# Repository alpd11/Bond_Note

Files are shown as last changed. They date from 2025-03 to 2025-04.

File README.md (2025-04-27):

<p align="center">
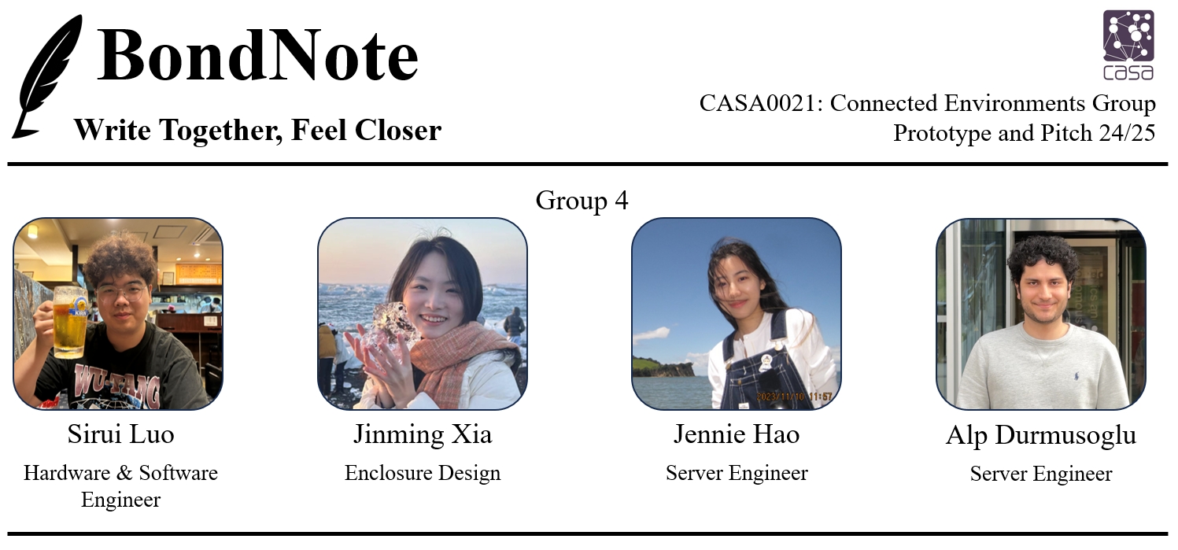
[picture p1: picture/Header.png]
Team
  <br>
</p>

### Project Video:
<p align="center">
  <a href="https://www.youtube.com/watch?v=klF6RZovyqQ" target="_blank">
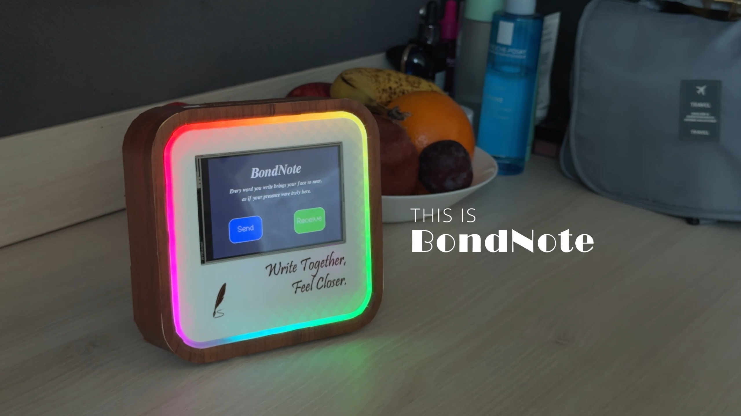
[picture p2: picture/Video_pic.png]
BondNote Video
    
  </a>
</p>

# ✍️ Whats is BondNote?
BondNote is a connected handwriting device designed to restore emotional warmth to digital communication (Fig.1). The project realises real-time transmission and dynamic reproduction of handwritten content by connecting two physical handwriting tablets. Its core design concept is ‘Bring warmth back into communication - because some messages deserve more than just text’.

<p align="center">
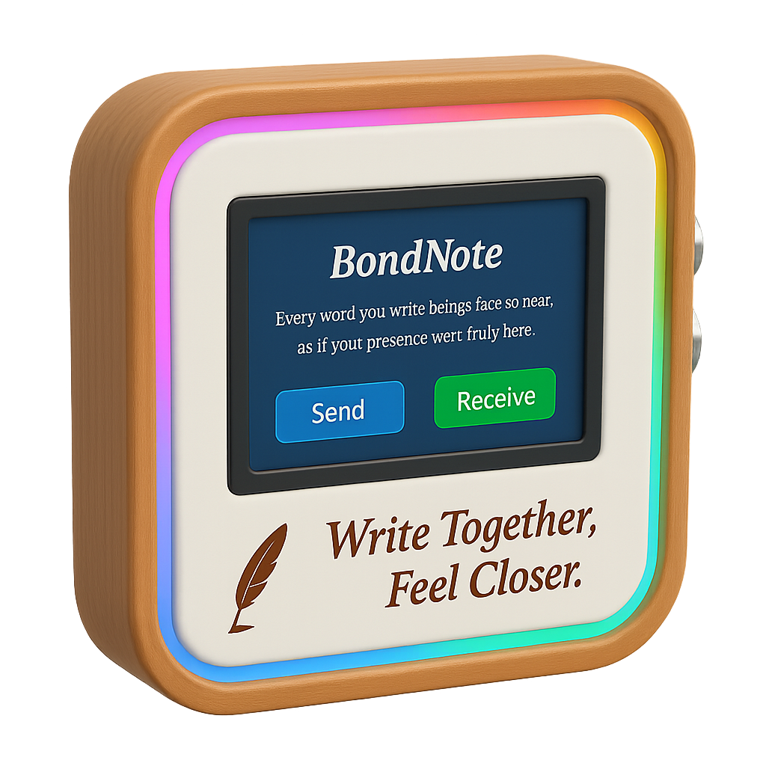
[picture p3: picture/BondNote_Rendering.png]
BondNote_Rendering
  <br>
  <span style="font-size: 14px; color: gray;"><b>Fig.1</b> BondNote rendering picture</span>
</p>

# 📑 Table of Contents

- [Why BondNote Is Useful](#-why-bondnote-is-useful)
- [Getting Started](#-getting-started)
- [How to use it](#-how-to-use-it)
- [Product Special Features](#-product-special-features)
- [Future Work](#-future-work)
- [Contributions](#-contributions)
- [Budget List](#-budget-list)
- [References](#references)

---

# 💡 Why BondNote Is Useful
<!-- 讲清楚使用场景、痛点与收益，展示价值主张。 -->
In today's digital world, the rapid development of technology has led to the gradual replacement of traditional handwriting by digital devices to dominate our conversations (Kiefer et al., 2015). Take WhatsApp, Messenger, and other popular instant messengers as an example, although they have greatly improved the efficiency of information transmission, they have become ‘flat’ because of their over-reliance on standardized text and emoticons. Different from the mechanical recognition of printed text, the writing and reading of handwritten text involve a complex process of linguistic and visual processing in the brain, and its personalized features carry emotional memory information (Ren et al., 2018).

In addition, the technology usability divide is particularly pronounced among specific groups. Pew Research Center (2017) found that 34% of older internet users say they have little to no confidence in their ability to use electronic devices to perform online tasks.
In the family scenario, parents often need to establish ‘lightweight’ remote communication with their younger children. However, existing solutions, such as equipping children with personal devices like smartphones, have many drawbacks. Children who are exposed to mobile phones early and excessively are more likely to have shortened attention spans, anxiety, and problems with social interactions (EdSource, 2024). Longcamp et al. (2005) showed that handwriting activities promote cognitive development by enhancing the perceptual-motor connection and helping children to better recognize and remember letters.

<p align="center">
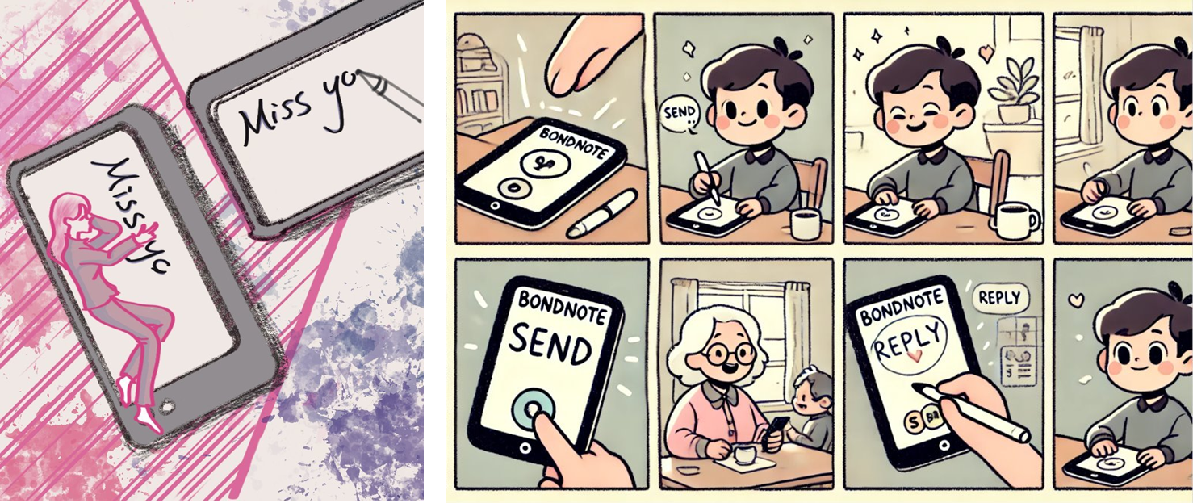
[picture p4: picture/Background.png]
  <br>
  <span style="font-size: 14px; color: gray;"><b>Fig.2</b> Target users</span>
</p>

Therefore, we identified the target users of our product (Fig.2):
-  ***Long-distance companions*** : need strong emotional connection and companionship, not cold digital information.
- ***The elderly and children***: need a simple and intuitive interactive system.

---
# 🚀 Getting Started

## Hardware List

To build and run this project, you will need the following hardware:

<div align="center">

| Item | Quantity | Description/Note |
|--- |:---:|---|
| **ESP32 DEVKITV1** | 1 | Main microcontroller board |
| **4-inch LCD TFT Touch Display** | 1 | ili9488 chip |
| **Buttons** | 2 | For user input |
| **WS2812 RGB LED Strip** | 1 | Individually addressable LEDs |
| **Power Supply** | 1 | For powering ESP32 and peripherals |
| **BondNote PCB** | 1 | Or it could be replaced as breadboard in Fig.3 |
| **Jumper wires** | multiple | Female-female, male-female, as needed |

</div>

***ps***: The BondNote PCB's Gerber file is in this repository. If you want to use this please upload this to any of the EDA manufacturers for building.

## Setup Steps

**1. Wiring:**  
<p align="center">
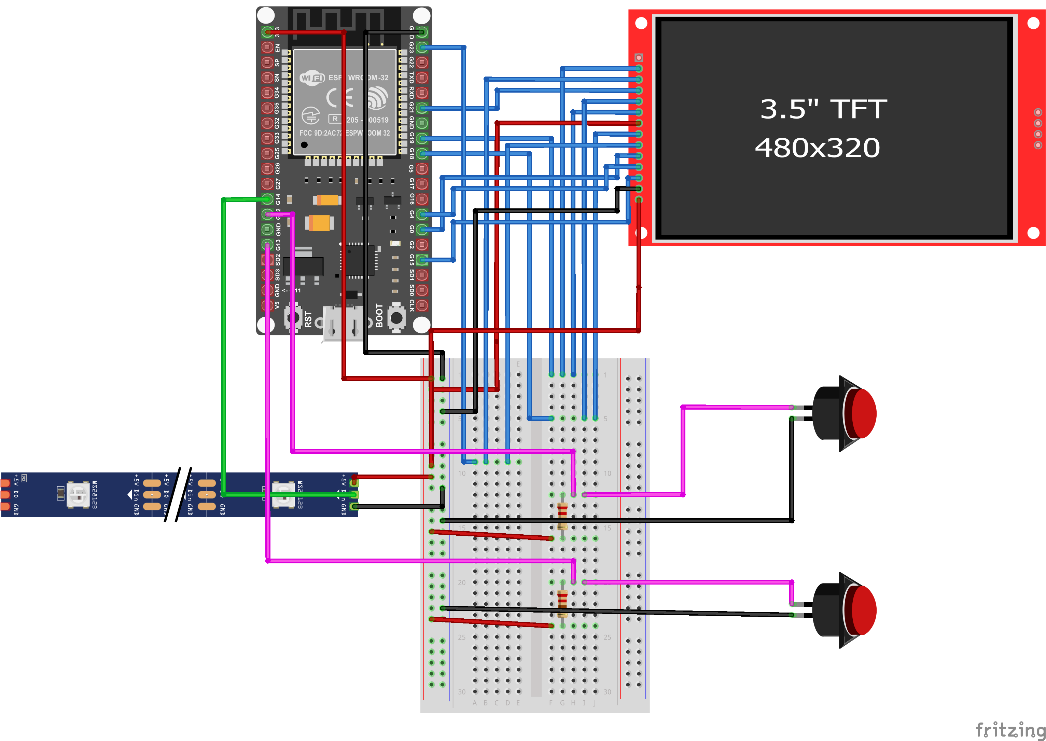
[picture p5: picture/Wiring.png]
  <br>
  <span style="font-size: 14px; color: gray;"><b>Fig.3</b> Wiring illustraion</span>
</p>

   - Connect the ESP32 to the LCD display following the ili9488 pinout.
   - Attach the two buttons to available digital pins on the ESP32 (remember to use pull-down or pull-up resistors as needed).
   - Connect the WS2812 LED strip data line to a suitable ESP32 GPIO, and provide appropriate power (typically 5V).
   - Power your ESP32 and peripherals using the power supply and jumper wires.

**2. Software Installation & Flashing the Code:**  
   - Install the [Arduino IDE](https://www.arduino.cc/en/software) on your computer.
   - Add the ESP32 board package to your IDE.
   - Install the necessary libraries:
     - `TFT_eSPI` (for ili9488 display)
     - `Adafruit_NeoPixel` (for WS2812 LED strip)
     - Clone this repository and flash **Bond_Note/BondNote_Code/BondNote.ino** to the ESP32 board

---
# 💻 How to use it
<p align="center">
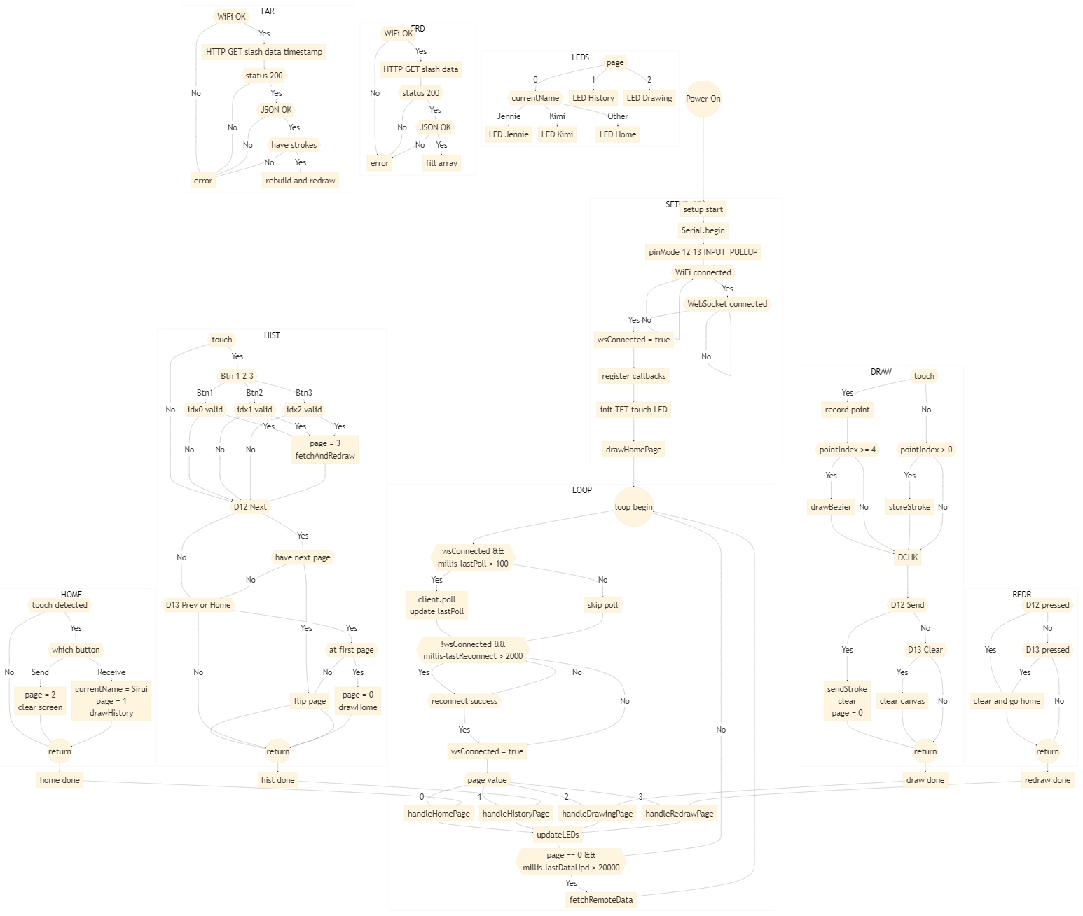
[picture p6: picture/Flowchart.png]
  <br>
  <span style="font-size: 14px; color: gray;"><b>Fig.4</b> Functions flowchart of BondNote</span>
</p>

The internal software of **BondNote** integrates a variety of functions and UI interfaces to ensure a warm and intuitive user experience. Below is a summary of the major functionalities and button interactions:

## ✉️ Core Functions: Sending and Receiving

### 1. Sending Handwritten Messages
- **Workflow:**
  - When the user clicks the "Send" button on the main interface, they enter the handwriting editing page.
  - On this page, users can freely write their message.
  - There are two physical buttons on the right side of the device:
    - **Upper button:** Confirm and send the current handwritten message.
    - **Lower button:** Erase the current handwriting (clear the canvas).

### 2. Receiving and Viewing Messages
- **Workflow:**
  - The Receive page provides a functional UI for browsing message history.
  - Users can use the two physical buttons to **page up** or **page down** through historical messages.
  - Messages from different senders are marked by their user name and distinct color (e.g., Jennie's messages in yellow, Kimi's messages in green).
  - After selecting a message, clicking it enters the "Redrawing" page, where the original handwriting process is dynamically displayed on the screen, enhancing the sense of real-time interaction.

## 🌈 Light Strip Notification & Real-time Listening

- On the welcome page, the software uses a WebSocket Echo listening function (`client.poll`) to constantly check for new messages from the server.
- When a new message is detected:
  - The sender's information is retrieved.
  - The RGB LED strip changes from a rainbow effect to a **breathing light** corresponding to the sender's color (e.g., Jennie = yellow breathing light, Kimi = green breathing light).
  - This real-time color change visually alerts users that a new message has arrived and helps identify the sender at a glance.

## 🔘 Button Interaction Overview
<div align="center">

| Page | Upper Button Function | Lower Button Function |
|---|---|---|
| **Welcome** | No response | No response |
| **Send** | Send message | Erase handwriting |
| **Receive** | Page up | Page down |
| **Message Redrawing** | Exit to Home | Exit to Home |

</div>

# 🌟 Product Special Features

## 🛠️ Hardware
**PCB Design & Fabrication:**  
<p align="center">
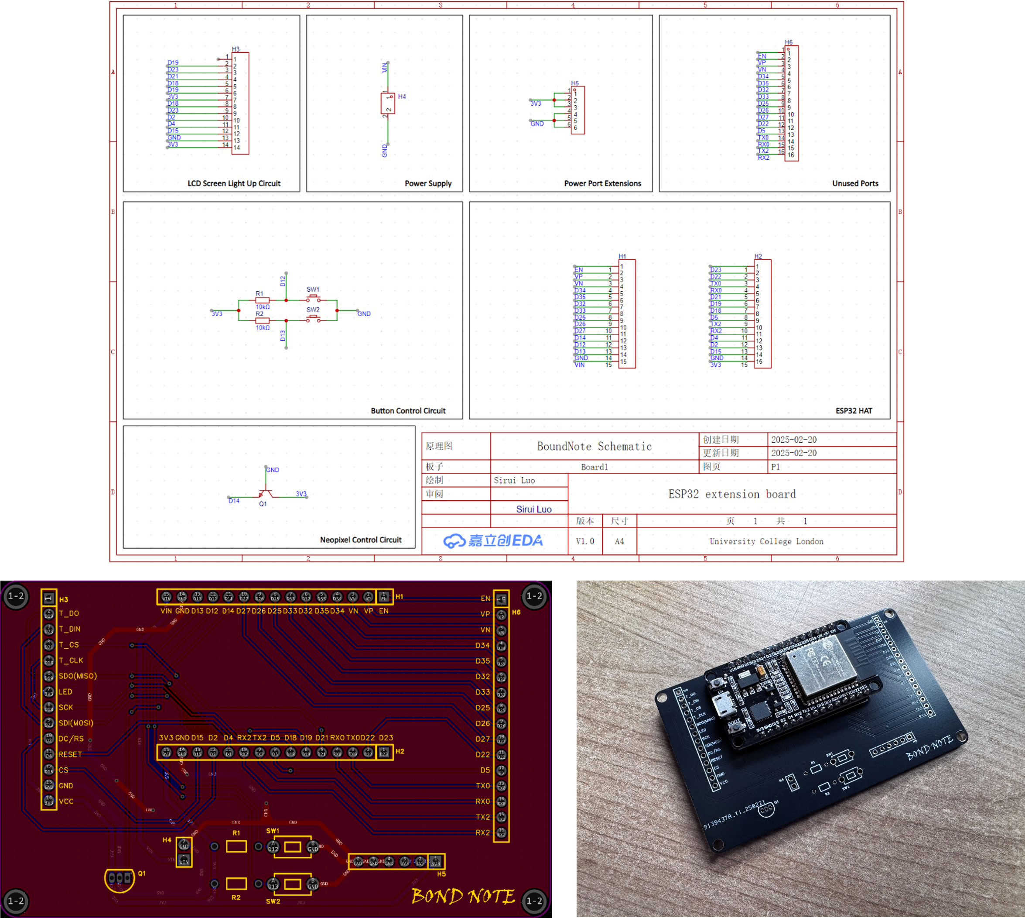
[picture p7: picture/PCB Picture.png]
  <br>
  <span style="font-size: 14px; color: gray;"><b>Fig.5</b> PCB schematic, wiring and material object</span>
</p>
We used EasyEDA Professional Edition to finish principle diagram drawing and PCB wiring design, and employed JLC international contract manufacturing service for PCB board manufacturing. The PCB board adopted the mode of expansion board design, and ESP32 DEVKIT1 development board was placed on the top layer. Then, connections with various components were designed based on different sectors to realize clear module division and efficient layout arrangement (Fig.5). 

## 💻 Software
**Real-time Communication:**  
BondNote once utilized the MQTT protocol in the early-stage design. However, the connection mode of MQTT is more suitable for light-weight data transmission, and it is not applicable to high-frequency data interaction. It can hardly realize the product's core function, namely synchronous handwriting trace representation. We finally chose WebSocket protocol as the alternative solution. 
WebSocket protocol can establish a permanent channel for real-time communication between the client end and the server, which significantly improves the response speed of application programs. It has characteristics like stabler long connection, lower transmission delay, etc., and it is particularly suitable for handwriting data transmission with manifest demands for real-time interactions. In addition, WebSocket can also manage multiple concurrent client end connections, which is vital for products needing simultaneous interactions among multiple users like BondNote.

**MongoDB and Heroku cloud platform integration:**  
As a NoSQL database, MongoDB is good at processing structured and semi-structured data, and it can store message coordinates, time stamps and users' information. It is very suitable for BondNote handwriting data coordinate storage. It can also provide powerful inquiry function, efficient data organization and fast interactive retrieval for users. 
Heroku, a cloud platform-as-a-service (PaaS), hosts the backend API, providing the necessary infrastructure for scalability, ease of deployment, and maintenance-free operation. The API hosted on Heroku seamlessly bridges the WebSocket protocol with MongoDB, enabling real-time data transactions between users and the database. Using Heroku’s managed services reduces operational overhead, ensures high availability, and facilitates continuous integration and deployment (CI/CD) practices, making it an ideal solution for Bond Note's infrastructure requirements.

**Structured Data Management:**  
Since the RAM space of ESP32 is relatively small, with limited processing capacity, we gave up the idea of using graphic data and turned to use light-weight Json format (Fig.8) to store and transmit handwriting data. During the process of storage and transmission, data coordinates are organized through time sequences to generate various arrays, which should be traversed in succession to realize real-time handwriting trace representation and guarantee efficient transmission and quick reading of data. 
<p align="center">
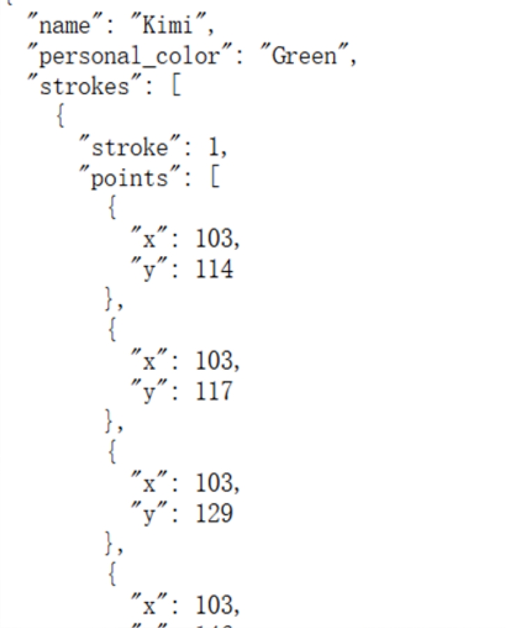
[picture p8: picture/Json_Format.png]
  <br>
  <span style="font-size: 14px; color: gray;"><b>Fig.6</b> Json formatted data</span>
</p>

**Handwriting Algorithm Optimization:**  
Since traditional eSPI library has poor ability of processing continuously handwriting traces, and the screen hardware's refresh rate is also limited, handwriting traces written by built-in functions in the library are always not ideal enough. Upon research, we found that Bezier curve algorithm can smoothly connect points with a short distance, thus significantly improving smoothness, while points with a long distance may be separated from integral handwriting through the dot painting function of eSPI.  The two can be combined to form a high-quality effect of handwriting (Fig.7). Moreover, this mode has lower computation loads, and there is basically no delay between writing and trace generation, which will not influence users' experience. 

<p align="center">
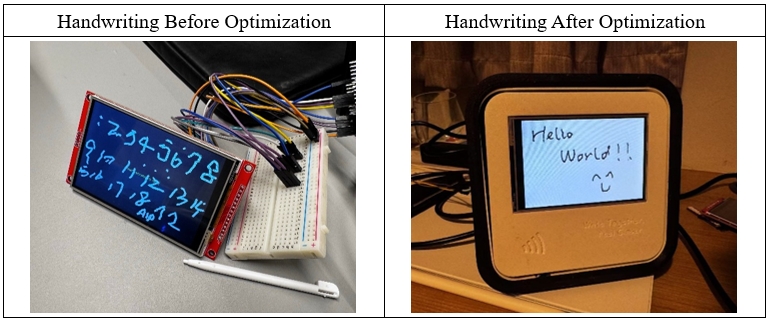
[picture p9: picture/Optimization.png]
  <br>
  <span style="font-size: 14px; color: gray;"><b>Fig.7</b> Before-and-after comparison pictures of optimization</span>
</p>

## 🧩 Model Design
BondNote’s enclosure was designed and modeled in SketchUp, undergoing multiple iterations to achieve a balance between function, emotional needs, and visual aesthetics. The initial design focused on portability and a slim profile, but as the project progressed, we wanted BondNote to stand out from ordinary electronic products and better express emotional warmth. Therefore, the enclosure was gradually redefined as a decorative ornament suitable for family spaces, endowing it with a sculptural sense to create a warmer atmosphere (Fig.8). 
<p align="center">
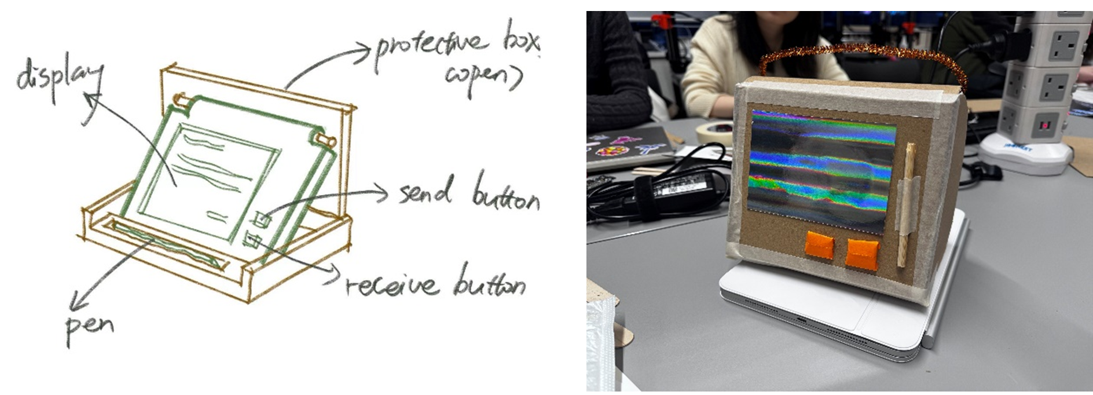
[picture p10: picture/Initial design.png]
  <br>
  <span style="font-size: 14px; color: gray;"><b>Fig.8</b> The initial design and improvements</span>
</p>

With continuous hardware upgrades, the enclosure was resized several times to ensure both comfortable handwriting and screen readability. The internal structure was also repeatedly refined to allow all components to remain stable while maintaining a glue-free assembly, making it easier to maintain and more environmentally friendly (Fig.9).

<p align="center">
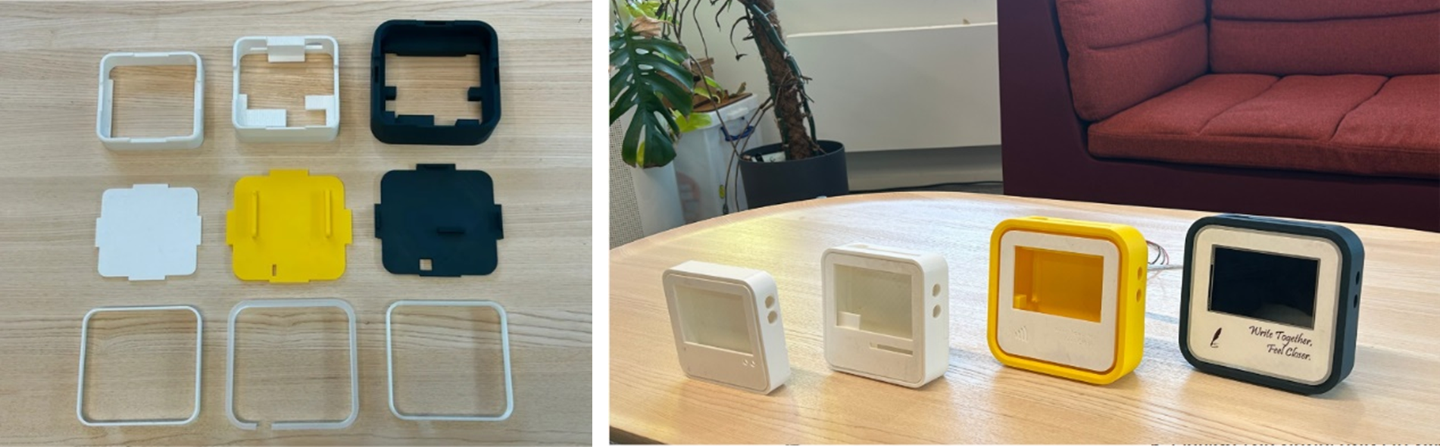
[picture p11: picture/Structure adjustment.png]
  <br>
  <span style="font-size: 14px; color: gray;"><b>Fig.9</b> Size, internal structure and placement angle adjustment</span>
</p>

 To further enhance the user experience, we introduced an inclined placement angle, improving both the ergonomics of handwriting and the clarity of displayed content in different scenarios. The design of the light slot was inspired by desk lamps: the original exposed light bar was upgraded into a concealed, soft-light band to better convey warmth. We explored different materials and surface treatments—such as using sandpaper for a diffused lighting effect—based on both our experiments and professors’ advice, ultimately achieving a gentle ambient glow (Fig.10). 

<p align="center">
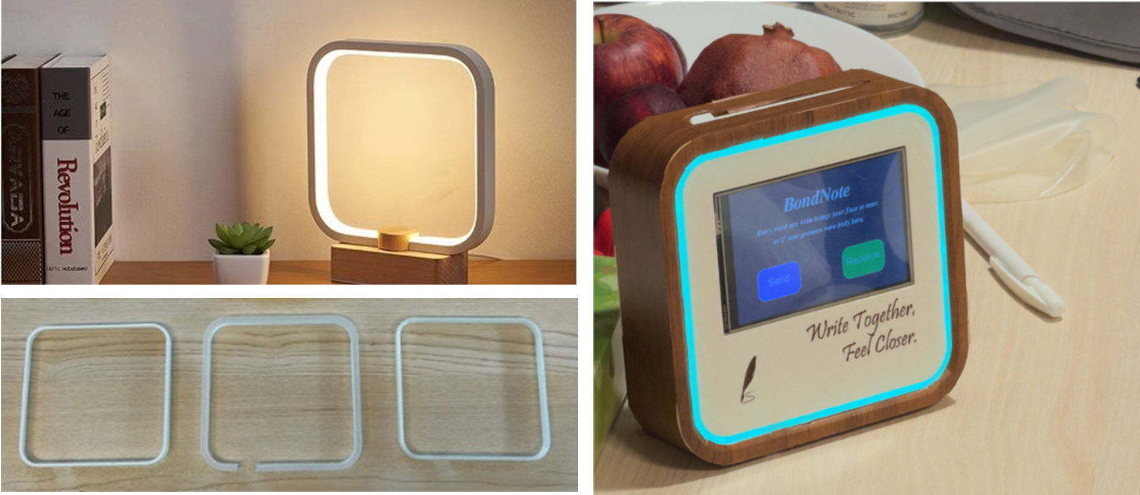
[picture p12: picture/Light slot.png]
  <br>
  <span style="font-size: 14px; color: gray;"><b>Fig.10</b> Light slot design optimization</span>
</p>

---

# 🔮 Future Work

## 3.1 Hardware Upgrade
In the future, we will consider customized and professional PCB production with a high degree of integration to lower costs and improve products' reliability. We will also establish long-term and stable cooperative relations with suppliers to guarantee the security of components' supply chains.

## 3.2 Software Function Expansion
We plan to provide more writing colors and the function of customization, develop mobile-end supporting App for BondNote, and provide functions like equipment initialization, monitoring and management to further improve users' experience.

## 3.3 Enclosure Improvement
In the future, the current PLA enclosure printed based on 3D printing technology may be upgraded as wooden materials to better reflect the product's feature of warm emotions and improve the product's market attraction and texture. 

---

# 🙌 Contributions

- **Sirui Luo:** Hardware selection, circuit construction, PCB design and manufacturing, all software development and deployment, as well as the script, filming, and editing of the project video. Readme file integration.
- **Jiniming Xia:** Enclosure design, manufacturing, and iteration. Project report integration.  Participated in the video as an actress.
- **Jennie Hao:** Server selection and setup, background research, and business analysis. Script formulation for video. Participated in the video as an actress.
- **Alp Durmusoglu:** Node.js server code development and MongoDB server setup and maintenance.

---

# 💰 Budget List

<div align="center">

| Item | Quantity | Price |
|---|:---:|:---:|
| **ESP32 DEVKITV1** | 1 | £7 |
| **4-inch LCD TFT Touch Display** | 1 | £22 |
| **Buttons** | 2 | £2.8 |
| **WS2812 RGB LED Strip** | 1 | £11 |
| **BondNote PCB / Breadboard** | 1 | £1 |
| **Jumper wires** | multiple | £1 |
| **3D Printed Enclosure** | 1 | ≈£5 |
| **Total** | — | **≈£49.8**|

</div>
<br>
PS：We need to deploy a server using Heroku, $5 for 1000 dyno hours/month

---

# 📑References

EdSource (2024) Excessive cell phone use can harm children. Here’s how parents can limit use at home. Available at: https://edsource.org/2024/excessive-cell-phone-use-can-harm-children-heres-how-parents-can-limit-use-at-home/718105 (Accessed: 24 April 2025).

Longcamp, M., Zerbato-Poudou, M.-T. & Velay, J.-L. (2005) The influence of writing practice on letter recognition in preschool children: A comparison between handwriting and typing. Acta Psychologica. 119 (1), 67–79. doi:10.1016/j.actpsy.2004.10.019.

Kiefer, M., Schuler, S., Mayer, C., Trumpp, N.M., Hille, K. & Sachse, S. (2015) Handwriting or Typewriting? The Influence of Penor Keyboard-Based Writing Training on Reading and Writing Performance in Preschool Children. Advances in Cognitive Psychology. 11, 136–146. doi:10.5709/acp-0178-7.

Pew Research Center (2017) Tech adoption climbs among older adults. Available at: https://www.pewresearch.org/internet/2017/05/17/tech-adoption-climbs-among-older-adults/ (Accessed: 24 April 2025).

Ren, X. Q., Fang, X., Sui, X. & Wu, Y. (2018) Characteristics and neural mechanisms of handwritten character recognition. Advances in Psychological Science, 26(7), 1174-1185. doi:10.3724/SP.J.1042.2018.01174

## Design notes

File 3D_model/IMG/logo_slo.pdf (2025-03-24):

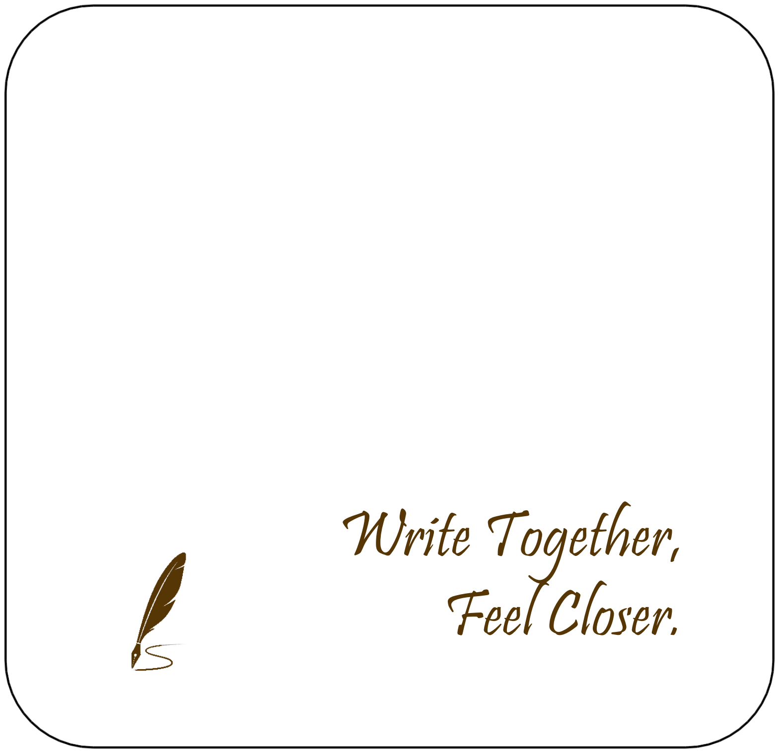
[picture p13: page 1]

WriteTogether,
FeelCloser.

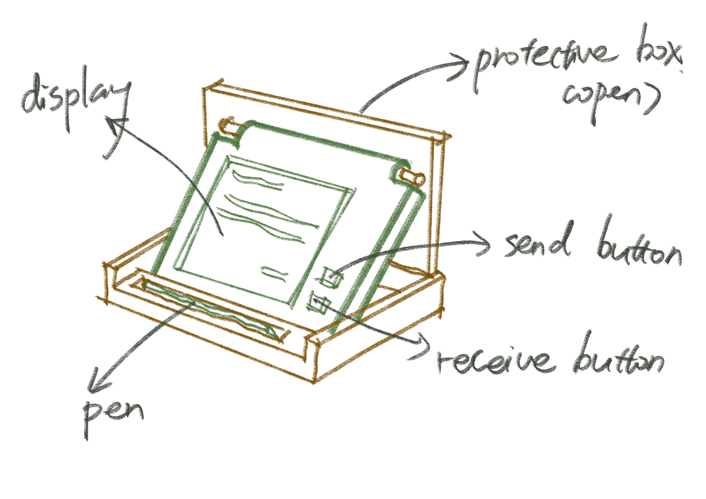
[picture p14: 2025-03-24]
3D_model/IMG/sketch1.jpg

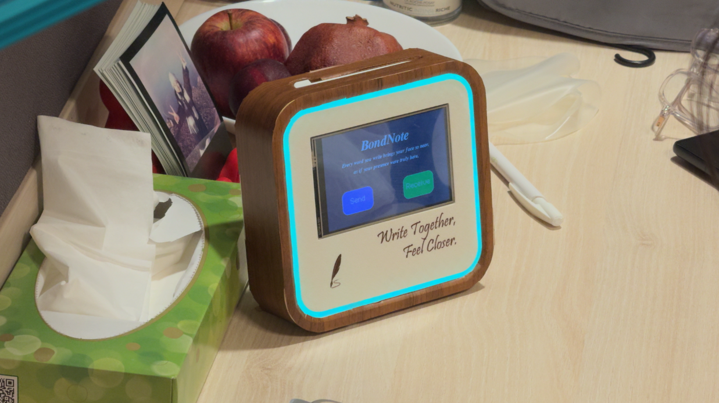
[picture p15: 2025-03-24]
3D_model/IMG/final2.png

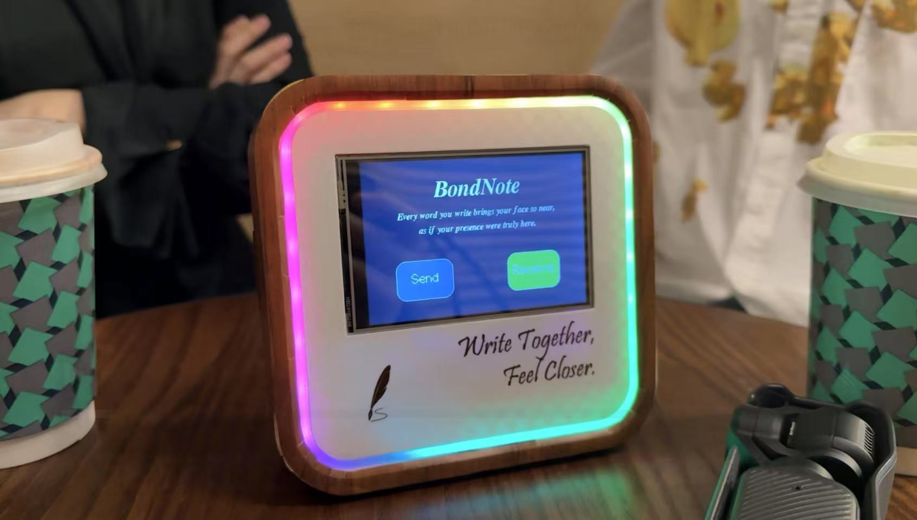
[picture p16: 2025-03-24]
3D_model/IMG/final.jpg

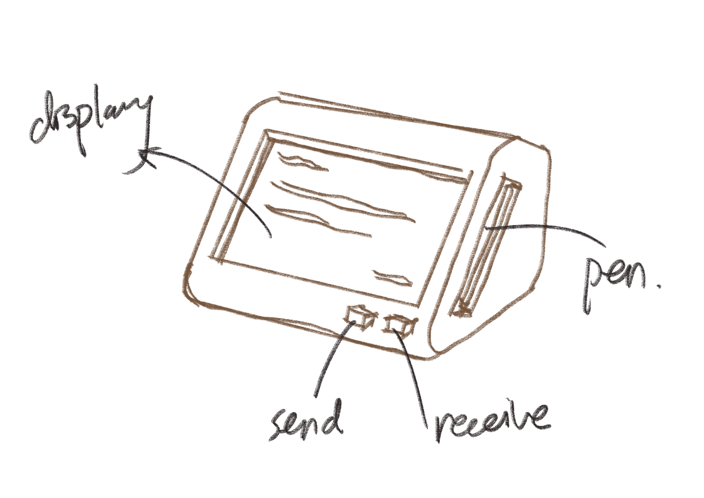
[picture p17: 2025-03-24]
3D_model/IMG/sketch3.jpg

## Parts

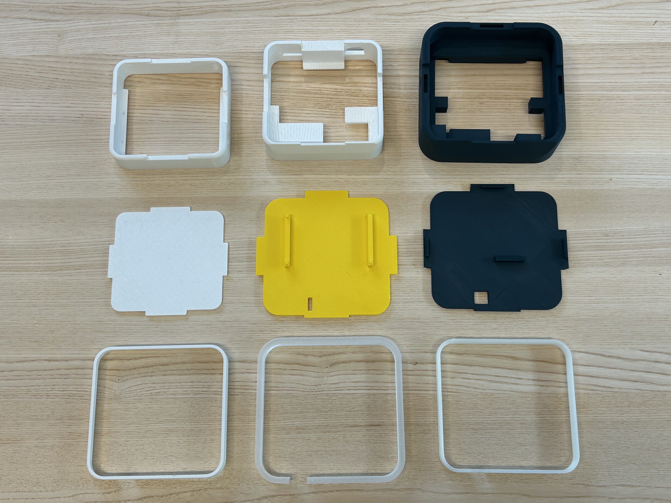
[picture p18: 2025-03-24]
3D_model/IMG/Components.jpg

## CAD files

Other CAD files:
3D_model/MODEL_TEST_0226.skp
3D_model/MODEL_TEST_0303.skp
3D_model/TILT_TEST_0306.skp

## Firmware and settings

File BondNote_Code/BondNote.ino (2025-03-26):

#include <TFT_eSPI.h>
#include <SPI.h>
#include <Arduino.h>
#include <ArduinoJson.h>
#include <WiFi.h>
#include <ArduinoWebsockets.h>
#include <Adafruit_NeoPixel.h>  
#include <HTTPClient.h>             
#include "Free_Fonts.h" 

using namespace websockets;

// **WiFi and WebSocket Configuration**

const char* ssid = "";      // Your WiFi SSID
const char* password = "";  // Your WiFi Password

// WebSocket server
const char* websockets_server_host = "bond-note-c746823b71f7.herokuapp.com";
const uint16_t websockets_server_port = 80;

WebsocketsClient client;
bool wsConnected = false; // WebSocket connection status
unsigned long lastPoll = 0;

// Create TFT_eSPI object
TFT_eSPI tft = TFT_eSPI();

// Two buttons on the home page
TFT_eSPI_Button btnSendMessage;
TFT_eSPI_Button btnReceiveMessage;

// Three buttons on the history messages page
TFT_eSPI_Button btnHistory1;
TFT_eSPI_Button btnHistory2;
TFT_eSPI_Button btnHistory3;

// Fixed known touch calibration data (example values)
uint16_t calData[5] = { 309, 3475, 243, 3519, 1 };

// Screen width and height
#define SCREEN_WIDTH  480
#define SCREEN_HEIGHT 320

// Width and height for each button
#define BTN_W SCREEN_WIDTH
#define BTN_H (SCREEN_HEIGHT / 3)

// Center coordinates for the three history buttons
#define BTN1_CX (SCREEN_WIDTH / 2)
#define BTN1_CY (BTN_H / 2)
#define BTN2_CX (SCREEN_WIDTH / 2)
#define BTN2_CY (BTN_H + BTN_H / 2)
#define BTN3_CX (SCREEN_WIDTH / 2)
#define BTN3_CY (2 * BTN_H + BTN_H / 2)

// Width and height for home page buttons
#define BTN_HOME_W (SCREEN_WIDTH / 4)
#define BTN_HOME_H (SCREEN_HEIGHT / 4)

// Center coordinates for home page buttons
#define BTN_SEND_CX (SCREEN_WIDTH / 4)
#define BTN_SEND_CY (SCREEN_HEIGHT * 3 / 4)
#define BTN_RECEIVE_CX (3 * SCREEN_WIDTH / 4)
#define BTN_RECEIVE_CY (SCREEN_HEIGHT * 3 / 4)

#define MAX_POINTS 100  
#define MAX_STROKES 100 
#define INACTIVITY_TIMEOUT 20000 // 5 seconds of no touch triggers redraw

// LED strip configuration (adjust LED_PIN based on actual wiring)
#define LED_PIN    5   
#define LED_COUNT  45  

Adafruit_NeoPixel strip(LED_COUNT, LED_PIN, NEO_GRB + NEO_KHZ800);

// ============ New: hardware button definitions ============
const int buttonPin12 = 12;  // GPIO12, using internal pull-up
const int buttonPin13 = 13;  // GPIO13, using internal pull-up

// ============ Variables for the writing page ============
uint16_t touchPoints[MAX_POINTS][2]; 
uint8_t pointIndex = 0;              
uint8_t thickness = 2;               
uint8_t strokeIndex = 1;             
unsigned long lastTouchTime = 0;     

struct Stroke {
  uint16_t points[MAX_POINTS][2];
  uint8_t pointCount;            
};
Stroke strokes[MAX_STROKES]; 
uint8_t strokeCount = 0;     

// ============ Page flags: 0-home, 1-history, 2-writing, 3-history strokes display ============
int page = 0;

// ========== Structure to store historical info fetched from the server ========== 
struct DataItem {
  String name;
  String timestamp;
};

#define MAX_DATA_ITEMS 20
DataItem dataItems[MAX_DATA_ITEMS];
int dataCount = 0;

// Refresh data every 5 seconds
unsigned long lastDataUpdate = 0;

// ========== History page pagination ==========
int historyStartIndex = 0;          // Current start index of the history list (0-based)
int buttonIndices[3] = {-1, -1, -1}; // Records the indices in dataItems for the 3 buttons

// ========== New: used to distinguish LED color on the home page ==========
String currentName = "None"; // Used to record the last "name" received from WebSocket

// ================ Function Declarations ================
void drawHomePage();
void drawHistoryPage();
void handleHomePage();
void handleHistoryPage();
void handleDrawingPage();
void handleRedrawPage(); // new

void setupWiFiAndWebSocket();
void fetchRemoteData();

uint32_t Wheel(byte WheelPos);
void updateLEDHome();
void updateLEDHistory();
void updateLEDDrawing();
void updateLEDKimi();
void updateLEDJennie();
void updateLEDs();

void sendStrokeData();
void redrawScreen();
void drawBezierCurve(uint16_t p0[], uint16_t p1[], uint16_t p2[], uint16_t p3[], uint16_t color);
void storeStroke();
void fetchAndRedraw(const String& timestamp);
void drawLoadingScreen();

void setup() {
  Serial.begin(115200);

  // Hardware buttons: internal pull-up
  pinMode(buttonPin12, INPUT_PULLUP);
  pinMode(buttonPin13, INPUT_PULLUP);

  // First connect to WiFi & WebSocket
  setupWiFiAndWebSocket();

  // Initialize screen
  tft.init();
  tft.setRotation(3);
  tft.setTouch(calData);
  tft.fillScreen(TFT_BLACK);

  // Initialize LED
  strip.begin();
  strip.show();
  strip.setBrightness(40); // Lower brightness to avoid glare

  // Draw the home page
  drawHomePage();
}

void loop() {
  // 1) Regardless of which page, periodically poll WebSocket
  if (millis() - lastPoll > 100 && wsConnected) {
    client.poll();
    lastPoll = millis();
  }

  // 2) If wsConnected == false, automatically attempt reconnection
  static unsigned long lastReconnectAttempt = 0;
  if (!wsConnected && millis() - lastReconnectAttempt >= 2000) {
    lastReconnectAttempt = millis();
    Serial.println("Trying to reconnect to WebSocket...");
    wsConnected = client.connect(websockets_server_host, websockets_server_port, "/");
    if (wsConnected) {
      Serial.println("✅ Reconnected!");
    } else {
      Serial.println("❌ Reconnect failed, will retry...");
    }
  }

  // 3) Handle interactions based on the current page
  if (page == 0) {
    handleHomePage();
  } 
  else if (page == 1) {
    handleHistoryPage();
  } 
  else if (page == 2) {
    handleDrawingPage();
  }
  else if (page == 3) {
    handleRedrawPage();
  }

  // 4) Update LEDs based on the current page
  updateLEDs();

  // 5) Periodically perform an HTTP GET to fetch data (only refresh when on home page)
  /*
  if (millis() - lastDataUpdate >= 20000 && page == 0) {
    lastDataUpdate = millis();
    fetchRemoteData();
  }
  */
}

// ================ WebSocket & WiFi Initialization ================
void setupWiFiAndWebSocket() {
  // 1. Connect to WiFi
  WiFi.begin(ssid, password);
  Serial.print("🔄 Connecting to WiFi...");
  while (WiFi.status() != WL_CONNECTED) {
      Serial.print(".");
      delay(1000);
  }
  Serial.println("\n✅ WiFi Connected!");

  // 2. Keep reconnecting WebSocket until successful
  Serial.print("🔄 Connecting to WebSocket Server...");
  while (!client.connect(websockets_server_host, websockets_server_port, "/")) {
      Serial.print(".");
      delay(1000);
  }
  wsConnected = true;
  Serial.println("\n✅ WebSocket Connected!");

  // 3. Set up callbacks
  client.onMessage([&](WebsocketsMessage message) {
      Serial.println("📩 WebSocket Received: " + message.data());

      // Attempt to parse JSON
      StaticJsonDocument<2048> doc;
      DeserializationError err = deserializeJson(doc, message.data());
      if (!err) {
        // If parsing is successful and "name" field exists
        if (doc.containsKey("name")) {
          String incomingName = doc["name"].as<String>();
          // Based on different "name", record to global variable currentName
          if (incomingName == "Jennie") {
            currentName = "Jennie";
            Serial.println("-> Detected name: Jennie");
            fetchRemoteData();
          }
          else if (incomingName == "Kimi") {
            currentName = "Kimi";
            Serial.println("-> Detected name: Kimi");
            fetchRemoteData();
          }
          else {
            // If neither Jennie nor Kimi, you can choose a default
            currentName = "None";
            Serial.println("-> Detected name: " + incomingName + " (ignored)");
          }
        }
      }
      else {
        // JSON parsing failed, do nothing
        Serial.println("❌ JSON parse error in WebSocket data!");
      }
  });

  client.onEvent([](WebsocketsEvent event, String data) {
      if (event == WebsocketsEvent::ConnectionClosed) {
          Serial.println("❌ WebSocket Connection Closed!");
          wsConnected = false; 
      }
  });
}

// ================ HTTP GET to fetch remote data ================
void fetchRemoteData() {
  if (WiFi.status() == WL_CONNECTED) {
    HTTPClient http;
    http.begin("http://bond-note-c746823b71f7.herokuapp.com/data");
    int httpCode = http.GET(); // Send GET request

    if (httpCode > 0) {
      if (httpCode == HTTP_CODE_OK) {
        String payload = http.getString();
        Serial.println("HTTP GET response:");
        Serial.println(payload);

        StaticJsonDocument<2048> doc;
        DeserializationError error = deserializeJson(doc, payload);
        if (!error) {
          JsonArray arr = doc.as<JsonArray>();
          dataCount = 0;
          for (JsonObject obj : arr) {
            if (dataCount >= MAX_DATA_ITEMS) break; 
            dataItems[dataCount].name = obj["name"].as<String>();
            dataItems[dataCount].timestamp = obj["timestamp"].as<String>();
            dataCount++;
          }
          Serial.println("✅ Data fetched and stored!");
        } else {
          Serial.print("❌ JSON parse error: ");
          Serial.println(error.c_str());
        }
      } else {
        Serial.printf("❌ HTTP GET... code: %d\n", httpCode);
      }
    } else {
      Serial.printf("❌ GET failed, error: %s\n", http.errorToString(httpCode).c_str());
    }
    http.end(); 
  } else {
    Serial.println("❌ WiFi not connected!");
  }
}

// ================ Draw the home page ================
void drawHomePage() {
  fetchRemoteData();

  tft.setTextSize(1);
  tft.fillScreen(TFT_BLACK);

  tft.setFreeFont(FSBI24);
  tft.setTextColor(TFT_WHITE, TFT_BLACK);

  int16_t stringWidth = tft.textWidth("BondNote", GFXFF);
  int16_t xpos = (SCREEN_WIDTH - stringWidth) / 2;
  int16_t ypos = 40;  
  tft.drawString("BondNote", xpos, ypos, GFXFF);

  tft.setFreeFont(FSBI9);
  tft.setTextColor(TFT_WHITE, TFT_BLACK);

  String line1 = "Every word you write brings your face so near,";
  int16_t line1Width = tft.textWidth(line1, GFXFF);
  int16_t line1_x = (SCREEN_WIDTH - line1Width) / 2;
  int16_t line1_y = ypos + tft.fontHeight(GFXFF) + 40;
  tft.drawString(line1, line1_x, line1_y, GFXFF);

  String line2 = "as if your presence were truly here.";
  int16_t line2Width = tft.textWidth(line2, GFXFF);
  int16_t line2_x = (SCREEN_WIDTH - line2Width) / 2;
  int16_t line2_y = line1_y + tft.fontHeight(GFXFF) + 8;
  tft.drawString(line2, line2_x, line2_y, GFXFF);

  tft.setFreeFont(NULL);
  tft.setTextFont(2);

  btnSendMessage.initButton(
    &tft, BTN_SEND_CX, BTN_SEND_CY, BTN_HOME_W, BTN_HOME_H,
    TFT_WHITE, TFT_BLUE, TFT_WHITE, (char*)"Send", 2
  );
  btnSendMessage.drawButton(false);

  btnReceiveMessage.initButton(
    &tft, BTN_RECEIVE_CX, BTN_RECEIVE_CY, BTN_HOME_W, BTN_HOME_H,
    TFT_WHITE, TFT_GREEN, TFT_WHITE, (char*)"Receive", 2
  );
  btnReceiveMessage.drawButton(false);
}

// ================ Draw the history page ================
void drawHistoryPage() {
  tft.fillScreen(TFT_BLACK);

  // A small function to format time
  auto formatTimestamp = [](const String &ts) -> String {
    // For example "2025-03-14T01:10:12.551Z" -> "2025-03-14, 01:10"
    if (ts.length() < 16) return ts; 
    String datePart = ts.substring(0, 10);
    String timePart = ts.substring(11, 16);
    return datePart + String(", ") + timePart;
  };

  // Before each redraw, clear buttonIndices
  for (int i = 0; i < 3; i++) {
    buttonIndices[i] = -1;
  }

  // Generate three rows of buttons corresponding to historyStartIndex through historyStartIndex+2
  for (int i = 0; i < 3; i++) {
    int itemIndex = historyStartIndex + i;

    // If out of range, show “-- No Data --”
    if (itemIndex >= dataCount) {
      switch (i) {
        case 0:
          btnHistory1.initButton(
            &tft, BTN1_CX, BTN1_CY, BTN_W, BTN_H,
            TFT_WHITE, TFT_DARKGREY, TFT_WHITE,
            (char*)"-- No Data --", 2
          );
          btnHistory1.drawButton(false);
          break;
        case 1:
          btnHistory2.initButton(
            &tft, BTN2_CX, BTN2_CY, BTN_W, BTN_H,
            TFT_WHITE, TFT_DARKGREY, TFT_WHITE,
            (char*)"-- No Data --", 2
          );
          btnHistory2.drawButton(false);
          break;
        case 2:
          btnHistory3.initButton(
            &tft, BTN3_CX, BTN3_CY, BTN_W, BTN_H,
            TFT_WHITE, TFT_DARKGREY, TFT_WHITE,
            (char*)"-- No Data --", 2
          );
          btnHistory3.drawButton(false);
          break;
      }
    } 
    else {
      // Based on itemIndex, get the corresponding name/time info
      String userName = dataItems[itemIndex].name;
      String timeStr  = formatTimestamp(dataItems[itemIndex].timestamp);
      String label    = timeStr + " by " + userName;

      // ====== Button color based on username ======
      uint16_t fillColor;
      if (userName == "Jennie") {
        // Bright yellow (can be adjusted)
        fillColor = tft.color565(255, 255, 0);
      }
      else if (userName == "Kimi") {
        // Bright green (can be adjusted)
        fillColor = tft.color565(0, 255, 0);
      }
      else {
        // If neither Jennie nor Kimi, use a default color. 
        // You could also assign based on i, for example.
        switch(i) {
          case 0: fillColor = TFT_BLUE;  break;
          case 1: fillColor = TFT_GREEN; break;
          case 2: fillColor = TFT_RED;   break;
        }
      }

      // ====== Generate buttons ======
      switch (i) {
        case 0:
          btnHistory1.initButton(
            &tft, BTN1_CX, BTN1_CY, BTN_W, BTN_H,
            TFT_WHITE, fillColor, TFT_WHITE,
            (char *)label.c_str(), 2
          );
          btnHistory1.drawButton(false);
          buttonIndices[0] = itemIndex;
          break;

        case 1:
          btnHistory2.initButton(
            &tft, BTN2_CX, BTN2_CY, BTN_W, BTN_H,
            TFT_WHITE, fillColor, TFT_WHITE,
            (char *)label.c_str(), 2
          );
          btnHistory2.drawButton(false);
          buttonIndices[1] = itemIndex;
          break;

        case 2:
          btnHistory3.initButton(
            &tft, BTN3_CX, BTN3_CY, BTN_W, BTN_H,
            TFT_WHITE, fillColor, TFT_WHITE,
            (char *)label.c_str(), 2
          );
          btnHistory3.drawButton(false);
          buttonIndices[2] = itemIndex;
          break;
      }
    }
  }
}


// ================ Handle interactions on the home page ================
void handleHomePage() {
  uint16_t tx, ty;
  bool touched = tft.getTouch(&tx, &ty);

  btnSendMessage.press(touched && btnSendMessage.contains(tx, ty));
  btnReceiveMessage.press(touched && btnReceiveMessage.contains(tx, ty));

  if (btnSendMessage.justPressed()) {
    btnSendMessage.drawButton(true);
    Serial.println("Send Message Pressed!");
    page = 2;
    tft.fillScreen(TFT_WHITE);
  }
  if (btnSendMessage.justReleased()) {
    btnSendMessage.drawButton(false);
  }

  if (btnReceiveMessage.justPressed()) {
    btnReceiveMessage.drawButton(true);
    Serial.println("Receive Message Pressed! Going to History Page...");

    // Reset page index to 0 before going to history page
    currentName = "Sirui";
    historyStartIndex = 0;
    page = 1;
    drawHistoryPage();
  }
  if (btnReceiveMessage.justReleased()) {
    btnReceiveMessage.drawButton(false);
  }
}

// ================ Handle interactions on the history page ================
void handleHistoryPage() {
  uint16_t tx, ty;
  bool touched = tft.getTouch(&tx, &ty);

  btnHistory1.press(touched && btnHistory1.contains(tx, ty));
  btnHistory2.press(touched && btnHistory2.contains(tx, ty));
  btnHistory3.press(touched && btnHistory3.contains(tx, ty));

  if (btnHistory1.justPressed()) {
    btnHistory1.drawButton(true);
    if (buttonIndices[0] >= 0 && buttonIndices[0] < dataCount) {
      Serial.println("History1 Pressed! -> index " + String(buttonIndices[0]));
      page = 3;
      fetchAndRedraw(dataItems[buttonIndices[0]].timestamp);
    }
  }
  if (btnHistory1.justReleased()) {
    btnHistory1.drawButton(false);
  }

  if (btnHistory2.justPressed()) {
    btnHistory2.drawButton(true);
    if (buttonIndices[1] >= 0 && buttonIndices[1] < dataCount) {
      Serial.println("History2 Pressed! -> index " + String(buttonIndices[1]));
      page = 3;
      fetchAndRedraw(dataItems[buttonIndices[1]].timestamp);
    }
  }
  if (btnHistory2.justReleased()) {
    btnHistory2.drawButton(false);
  }

  if (btnHistory3.justPressed()) {
    btnHistory3.drawButton(true);
    if (buttonIndices[2] >= 0 && buttonIndices[2] < dataCount) {
      Serial.println("History3 Pressed! -> index " + String(buttonIndices[2]));
      page = 3;
      fetchAndRedraw(dataItems[buttonIndices[2]].timestamp);
    }
  }
  if (btnHistory3.justReleased()) {
    btnHistory3.drawButton(false);
  }

  // ======== New: detect D12 and D13 on the history page to control pagination ========
  if (digitalRead(buttonPin12) == LOW) {
    // D12: next page
    Serial.println("D12 Pressed -> Next Page of History");
    if (historyStartIndex + 3 < dataCount) {
      historyStartIndex += 3;
      drawHistoryPage();
    } else {
      Serial.println("Already at last page, no further data.");
    }
    delay(300); // Debounce
  }

  if (digitalRead(buttonPin13) == LOW) {
    // D13: previous page / or go back to home
    Serial.println("D13 Pressed -> Prev Page or Home");
    if (historyStartIndex == 0) {
      page = 0;
      drawLoadingScreen();
      drawHomePage();
    } else {
      historyStartIndex -= 3;
      if (historyStartIndex < 0) {
        historyStartIndex = 0; 
      }
      drawHistoryPage();
    }
    delay(300); // Debounce
  }
}

// ================ Handle interactions on the writing page ================
void handleDrawingPage() {
  uint16_t x, y;
  if (tft.getTouch(&x, &y)) {
    lastTouchTime = millis();
    if (pointIndex < MAX_POINTS) {
      touchPoints[pointIndex][0] = x;
      touchPoints[pointIndex][1] = y;
      pointIndex++;
    }
    if (pointIndex >= 4) {
      uint16_t *p0 = touchPoints[pointIndex - 4];
      uint16_t *p1 = touchPoints[pointIndex - 3];
      uint16_t *p2 = touchPoints[pointIndex - 2];
      uint16_t *p3 = touchPoints[pointIndex - 1];
      drawBezierCurve(p0, p1, p2, p3, TFT_BLACK);
    }
  } 
  else {
    // Finger lifted, store stroke
    if (pointIndex > 0) {
      storeStroke();
      strokeIndex++;
    }
  }

  // Detect button presses
  if (digitalRead(buttonPin12) == LOW) {
    Serial.println("D12 Pressed -> Send Data & Go Home");
    // 1) Send stroke data
    sendStrokeData();

    // 2) Reset arrays
    memset(touchPoints, 0, sizeof(touchPoints));
    memset(strokes, 0, sizeof(strokes));

    // 3) Other reset operations
    page = 0;          
    strokeCount = 0;  
    pointIndex = 0;   
    strokeIndex = 1;   
    
    // 4) Return to home page and debounce
    drawLoadingScreen();
    drawHomePage();   
  }

  if (digitalRead(buttonPin13) == LOW) {
    Serial.println("D13 Pressed -> Clear Strokes");
    memset(touchPoints, 0, sizeof(touchPoints));
    memset(strokes, 0, sizeof(strokes));
    strokeCount = 0;  
    pointIndex = 0; 
    strokeIndex = 1;   
    tft.fillScreen(TFT_WHITE);
    delay(300);       
  }
}

// ================ Handle interactions on the history stroke redraw page ================
void handleRedrawPage(){
  if (digitalRead(buttonPin12) == LOW) {
    Serial.println("D12 Pressed -> Go Home");
    memset(touchPoints, 0, sizeof(touchPoints));
    memset(strokes, 0, sizeof(strokes));

    page = 0;          
    strokeCount = 0;  
    pointIndex = 0;   
    strokeIndex = 1;   
    
    drawLoadingScreen();  
    drawHomePage();        
  }

  if (digitalRead(buttonPin13) == LOW) {
    Serial.println("D13 Pressed -> Clear & Go Home");
    memset(touchPoints, 0, sizeof(touchPoints));
    memset(strokes, 0, sizeof(strokes));

    page = 0;          
    strokeCount = 0;  
    pointIndex = 0;   
    strokeIndex = 1;   
    drawLoadingScreen();
    drawHomePage();      
  }
}

// ================ Bezier curve interpolation drawing ================
void drawBezierCurve(uint16_t p0[], uint16_t p1[], uint16_t p2[], uint16_t p3[], uint16_t color) {
  for (float t = 0; t <= 1; t += 0.1) {
    float x = (1 - t)*(1 - t)*(1 - t)*p0[0] +
              3*(1 - t)*(1 - t)*t*p1[0] +
              3*(1 - t)*t*t*p2[0] +
              t*t*t*p3[0];
    float y = (1 - t)*(1 - t)*(1 - t)*p0[1] +
              3*(1 - t)*(1 - t)*t*p1[1] +
              3*(1 - t)*t*t*p2[1] +
              t*t*t*p3[1];
    tft.fillCircle(x, y, thickness, color);
  }
}

// ================ Store a stroke ================
void storeStroke() {
  if (pointIndex == 0) return;
  if (strokeCount < MAX_STROKES) {
    memcpy(strokes[strokeCount].points, touchPoints, pointIndex * sizeof(touchPoints[0]));
    strokes[strokeCount].pointCount = pointIndex;
    strokeCount++;
  }
  pointIndex = 0; 
}

// ================ Generate JSON and send via WebSocket ================
void sendStrokeData() {
  if (strokeCount == 0) {
    Serial.println("No strokes to send, skipping...");
    return;
  }

  StaticJsonDocument<4096> jsonDoc;
  jsonDoc["name"] = "Jennie";         // Change to your name if desired
  jsonDoc["personal_color"] = "Yellow";

  JsonArray strokesArray = jsonDoc.createNestedArray("strokes");
  for (uint8_t i = 0; i < strokeCount; i++) {
    JsonObject strokeObj = strokesArray.createNestedObject();
    strokeObj["stroke"] = i + 1;
    JsonArray pointsArray = strokeObj.createNestedArray("points");
    for (uint8_t j = 0; j < strokes[i].pointCount; j++) {
      JsonObject pointObj = pointsArray.createNestedObject();
      pointObj["x"] = strokes[i].points[j][0];
      pointObj["y"] = strokes[i].points[j][1];
    }
  }

  String jsonString;
  serializeJson(jsonDoc, jsonString);
  if (wsConnected) {
    client.send(jsonString);
    Serial.println("📤 JSON Sent: " + jsonString);
  } else {
    Serial.println("❌ WebSocket Not Connected, Cannot Send Data");
  }
}
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

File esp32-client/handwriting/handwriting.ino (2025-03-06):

#include <ArduinoWebsockets.h>
#include <WiFi.h>

const char* ssid = "CE-Hub-Student";                                        // WiFi SSID
const char* password = "casa-ce-gagarin-public-service";                    // WiFi Password
const char* websockets_server_host = "hmltry1-1e722cd26d62.herokuapp.com";  // WebSocket Address
const uint16_t websockets_server_port = 80;                                 // WebSocket Port

using namespace websockets;

WebsocketsClient client;
unsigned long lastSendTime = 0;  // Record the time of the last dispatch

void setup() {
  Serial.begin(115200);
  WiFi.begin(ssid, password);

  // Waiting for WiFi connection
  for (int i = 0; i < 10 && WiFi.status() != WL_CONNECTED; i++) {
  Serial.print(".");
  delay(1000);
  }

  if (WiFi.status() != WL_CONNECTED) {
    Serial.println("❌ No Wifi!");
    return;
  }

  Serial.println("\n✅ Connected to Wifi, Connecting to server...");

  // Connect WebSocket Server
  bool connected = client.connect(websockets_server_host, websockets_server_port, "/");
  if (connected) {
    Serial.println("✅ WebSocket Connected!");
    client.send("Hello Server");
  } else {
    Serial.println("❌ WebSocket Not Connected!");
  }

  // Habdle messages received from WebSocket
  client.onMessage([&](WebsocketsMessage message) {
    Serial.print("📩 Got Message: ");
    Serial.println(message.data());
  });
}

void loop() {
  // Let the WebSocket client check the message
  if (client.available()) {
  client.poll();
  }

  // A message is sent every 1 second
  if (millis() - lastSendTime >= 1000) {
  lastSendTime = millis();
  String message = "ESP32 发送的数据: " + String(millis());
  Serial.println("📤 发送消息: " + message);
  client.send(message);
  }

  delay(10);  // reduce CPU load
}

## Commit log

2025-03-03 web socket server added
2025-03-04 Websocket runs, but cannot connect with ESP32.
2025-03-06 tilt test add
    [MODEL_TEST_0303.skp, TILT_TEST_0306.skp]
